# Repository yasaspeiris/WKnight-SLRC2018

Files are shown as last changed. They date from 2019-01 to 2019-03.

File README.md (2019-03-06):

# WKnight-SLRC2018



WKnight was made to compete in the Sri Lankan Robotics Challenge organized by the University of Moratuwa. 
The structure of this repo is as follows.

### Parts
Contains the STL files for the 3D printable parts. This includes the base, coin picking mechanism and gearing system.

3dp

### SLRC2019
This folder contains the code (for an Atmega2560). Each core component is split into a seperate .ino file. 

*colorsetup - Helper function for the colour sensor

*lightsandsw - Lights and switches

*main

*motorsetup - Contains motor control functions, white line/ wall / encoder PID Functions

*nrfsetup - NRF24L functions for wireless communication with a stationary robot

*path - path minimization

*QTRC - calibration and helper functions for the Pololu QTRC panel

*servosetup - servo control

*SLRC2019_19_Edited - global variables and definitions

*sonarsetup - ultrasonic sensor setup and control

*vlxsetup - TOF sensor (not used)

*wallfollow - wall following (not used)

### WKnightMEGA Breakout Board 
A breakout board for the Atmega2560 development board.



Full Instructions will be updated soon.

## Contributors
Pasindu Liyanage

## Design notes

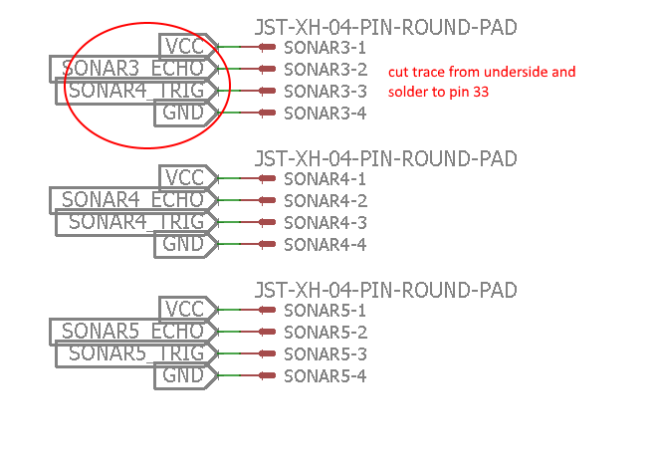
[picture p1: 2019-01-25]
WKnightMEGA - Breakout Board/sonarfix.png

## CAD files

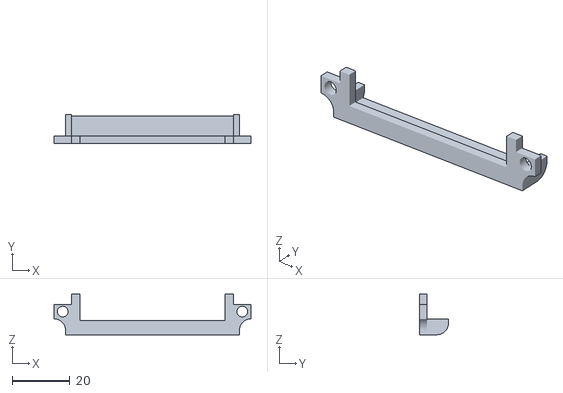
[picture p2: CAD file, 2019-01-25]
Parts/qtrcholder_main.STL
68.0 x 10.0 x 14.0

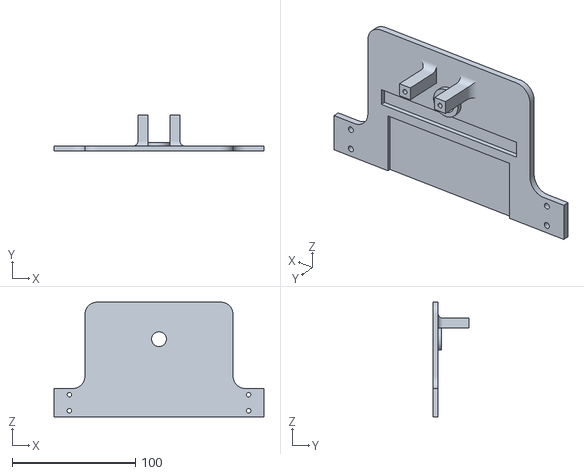
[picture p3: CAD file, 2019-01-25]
Parts/mainbed.STL
170.1 x 29.0 x 93.0

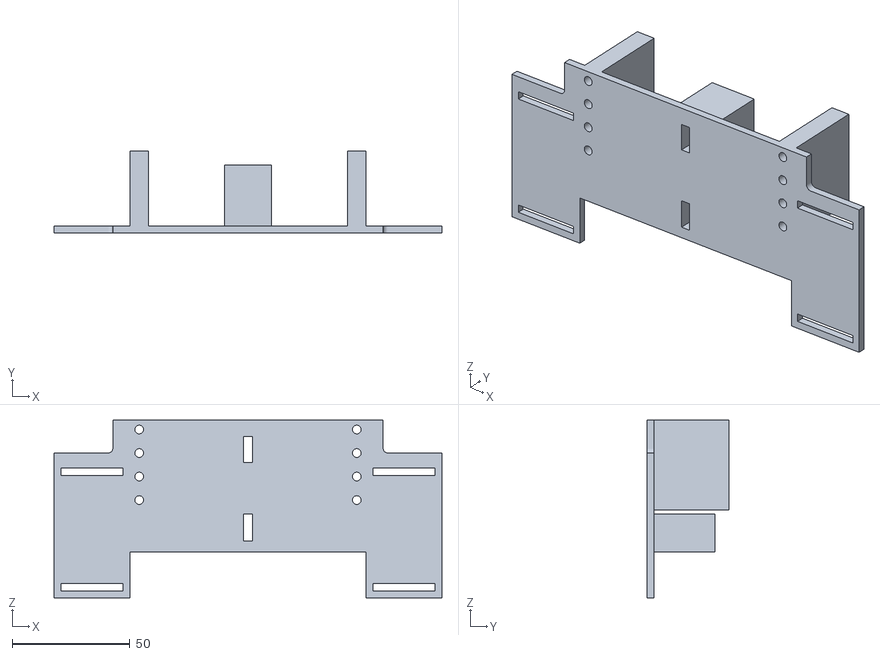
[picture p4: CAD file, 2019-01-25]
Parts/servomountfront.STL
165.0 x 35.0 x 75.6

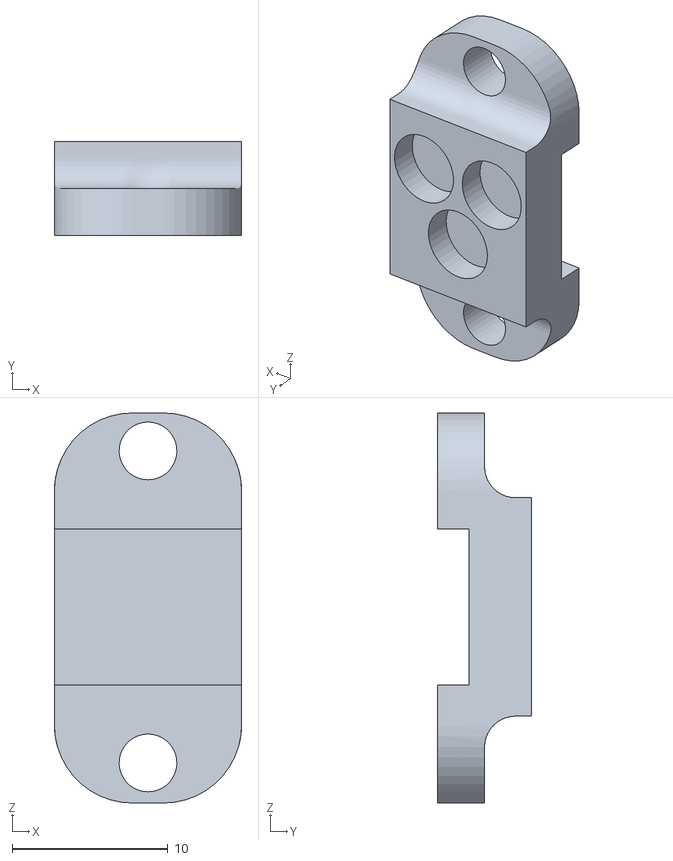
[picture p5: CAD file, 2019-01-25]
Parts/lightholder.STL
12.0 x 6.00 x 25.0

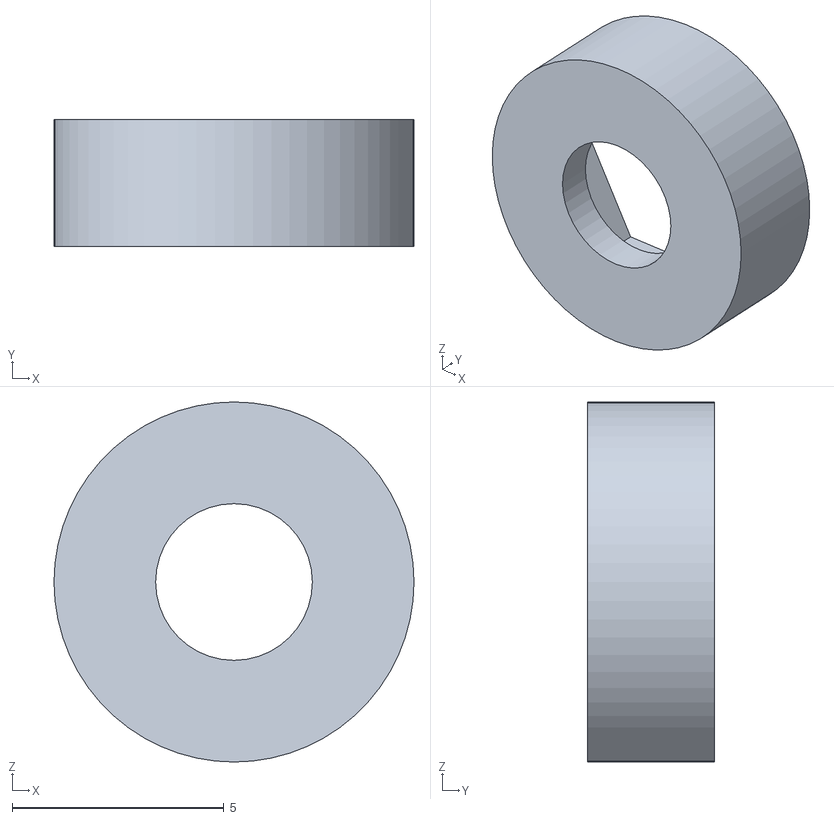
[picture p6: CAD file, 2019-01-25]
Parts/nutholder.STL
8.50 x 3.00 x 8.50

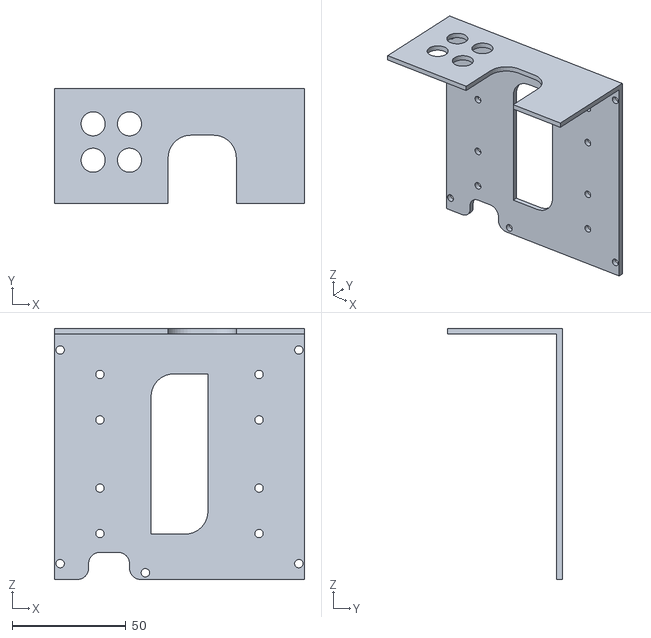
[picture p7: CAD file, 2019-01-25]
Parts/upper_cover.STL
110.0 x 50.5 x 110.5

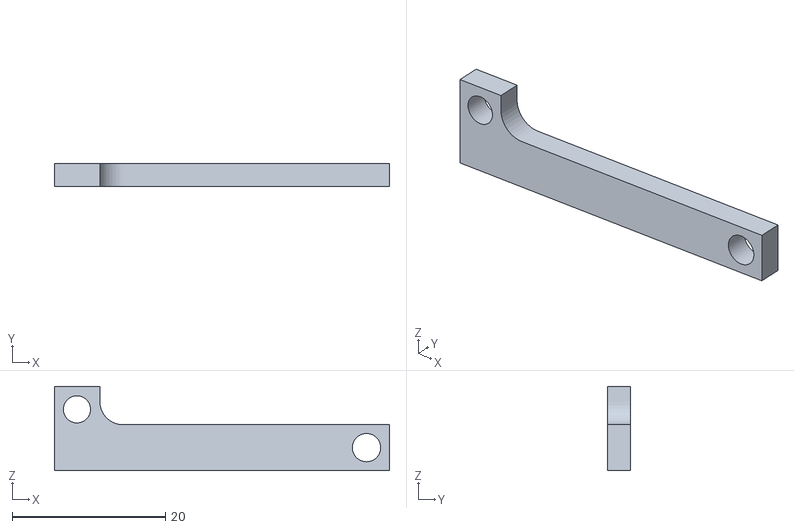
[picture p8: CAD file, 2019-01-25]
Parts/batlock.STL
43.8 x 3.00 x 11.0

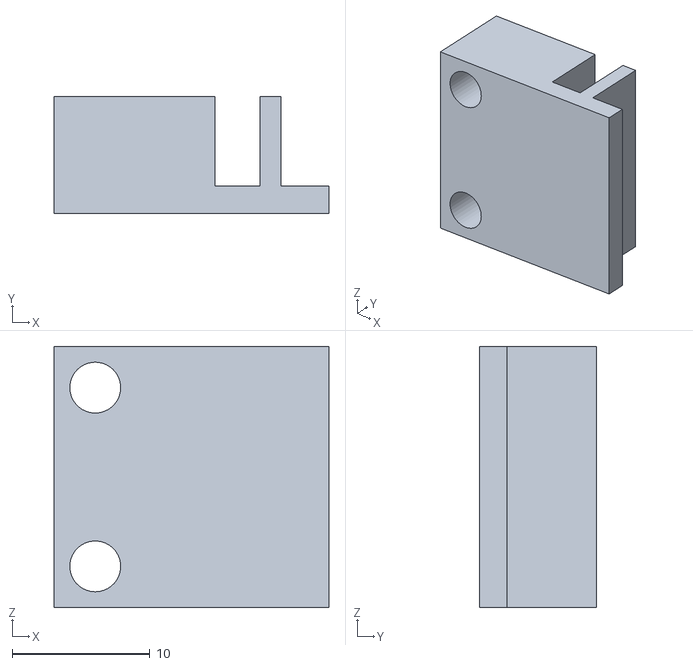
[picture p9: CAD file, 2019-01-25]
Parts/lockblock.STL
20.0 x 8.50 x 19.0

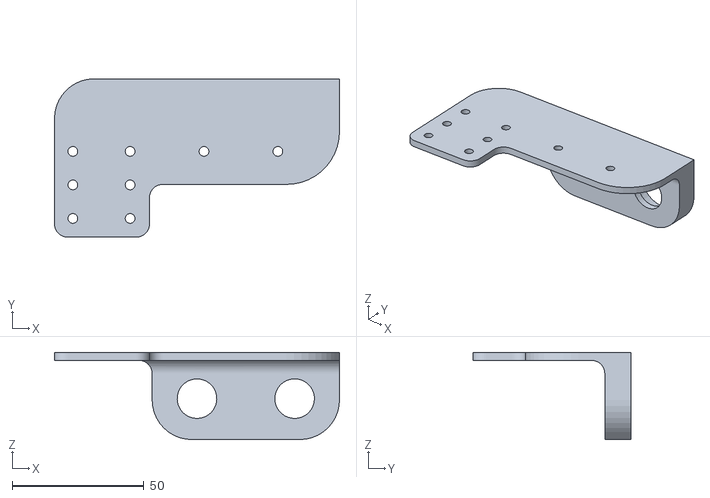
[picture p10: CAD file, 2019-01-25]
Parts/experimental_bracket.STL
108.0 x 60.0 x 33.0

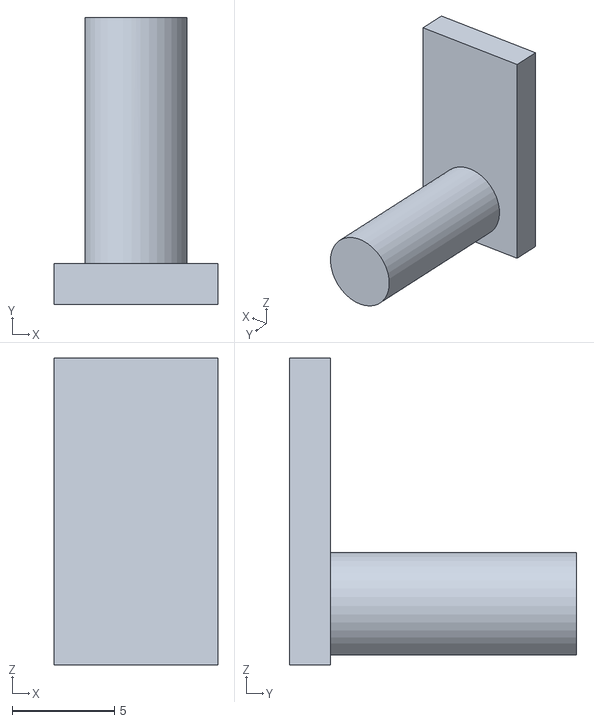
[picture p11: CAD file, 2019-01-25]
Parts/handle.STL
8.00 x 14.0 x 15.0

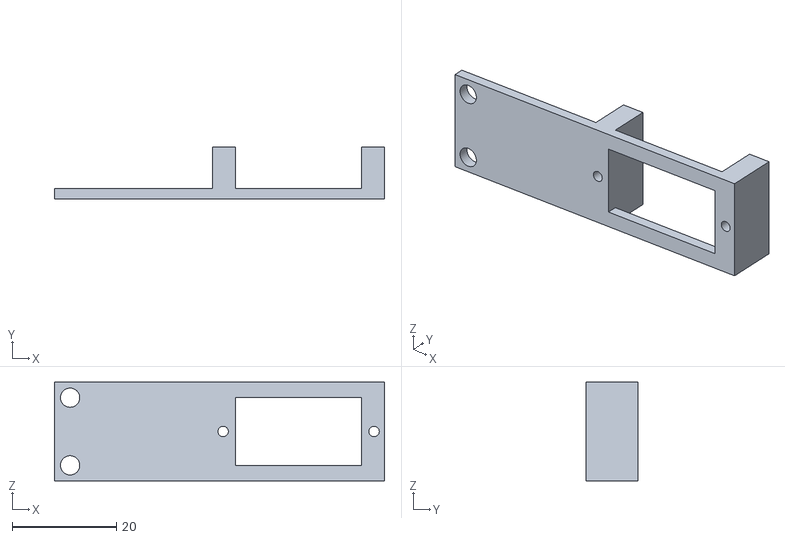
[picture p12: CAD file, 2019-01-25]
Parts/servoholder.STL
63.4 x 10.0 x 19.0

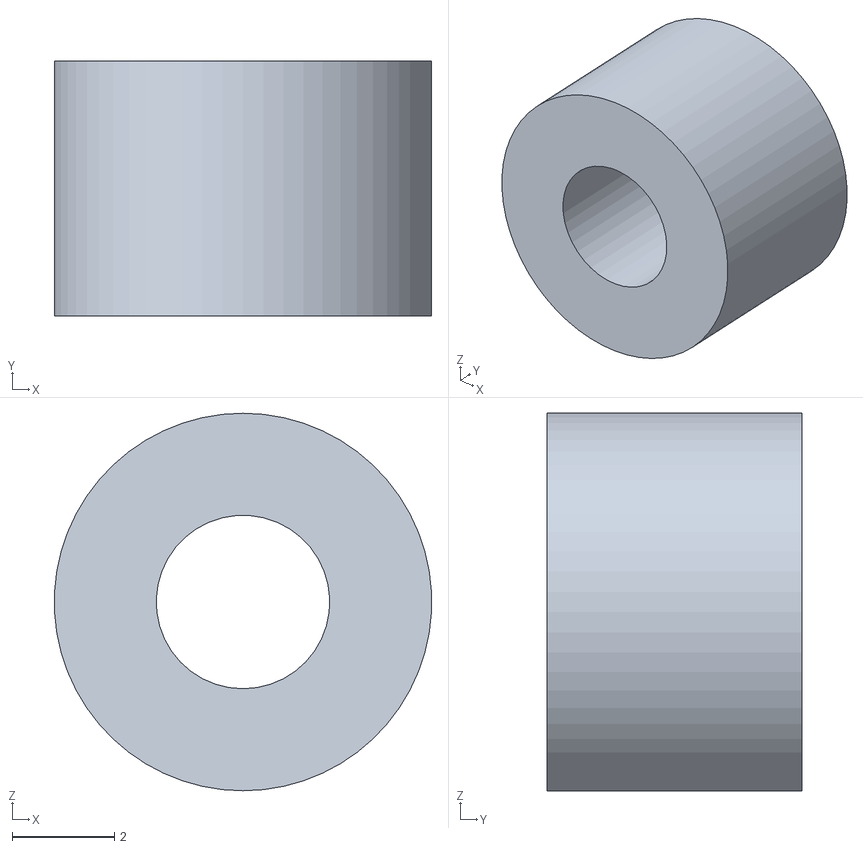
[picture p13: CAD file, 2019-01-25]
Parts/spacer2.STL
7.39 x 5.00 x 7.40

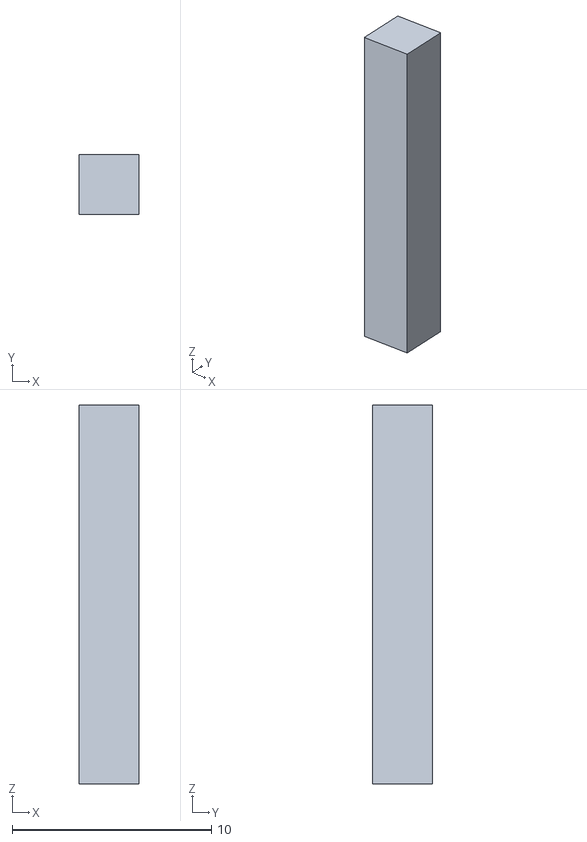
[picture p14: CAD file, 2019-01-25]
Parts/midspacer.STL
3.00 x 3.00 x 19.0

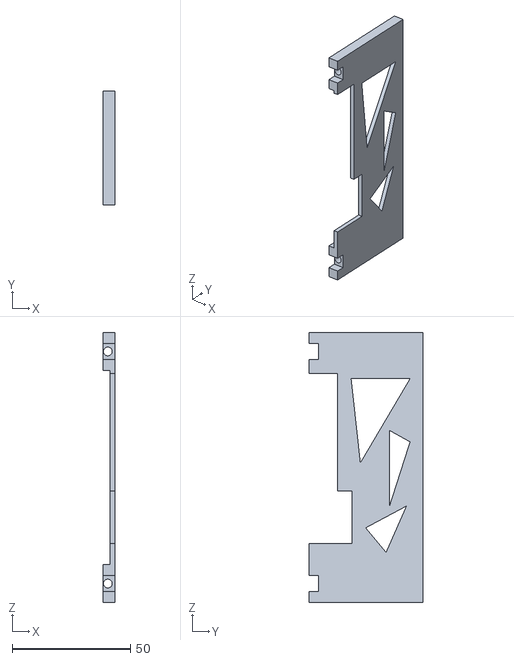
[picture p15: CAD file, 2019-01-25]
Parts/leftsidewall.STL
5.00 x 48.0 x 114.0

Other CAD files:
Parts/midgear.STL
Parts/rack1.STL
Parts/batterymount.STL
Parts/bearingspacer_new_2.STL
Parts/base.STL
Parts/base_top1-newnew.STL
Parts/coinremover.STL
Parts/compartment.STL
Parts/compcover1.STL
Parts/experimental_motorgear.STL
Parts/qtrcholder_sub.STL
Parts/rightsidewall.STL
Parts/spacer.STL
Parts/spurgear.STL
Parts/spurgear2.STL
Parts/trayeject.STL
Parts/wheelgear.STL

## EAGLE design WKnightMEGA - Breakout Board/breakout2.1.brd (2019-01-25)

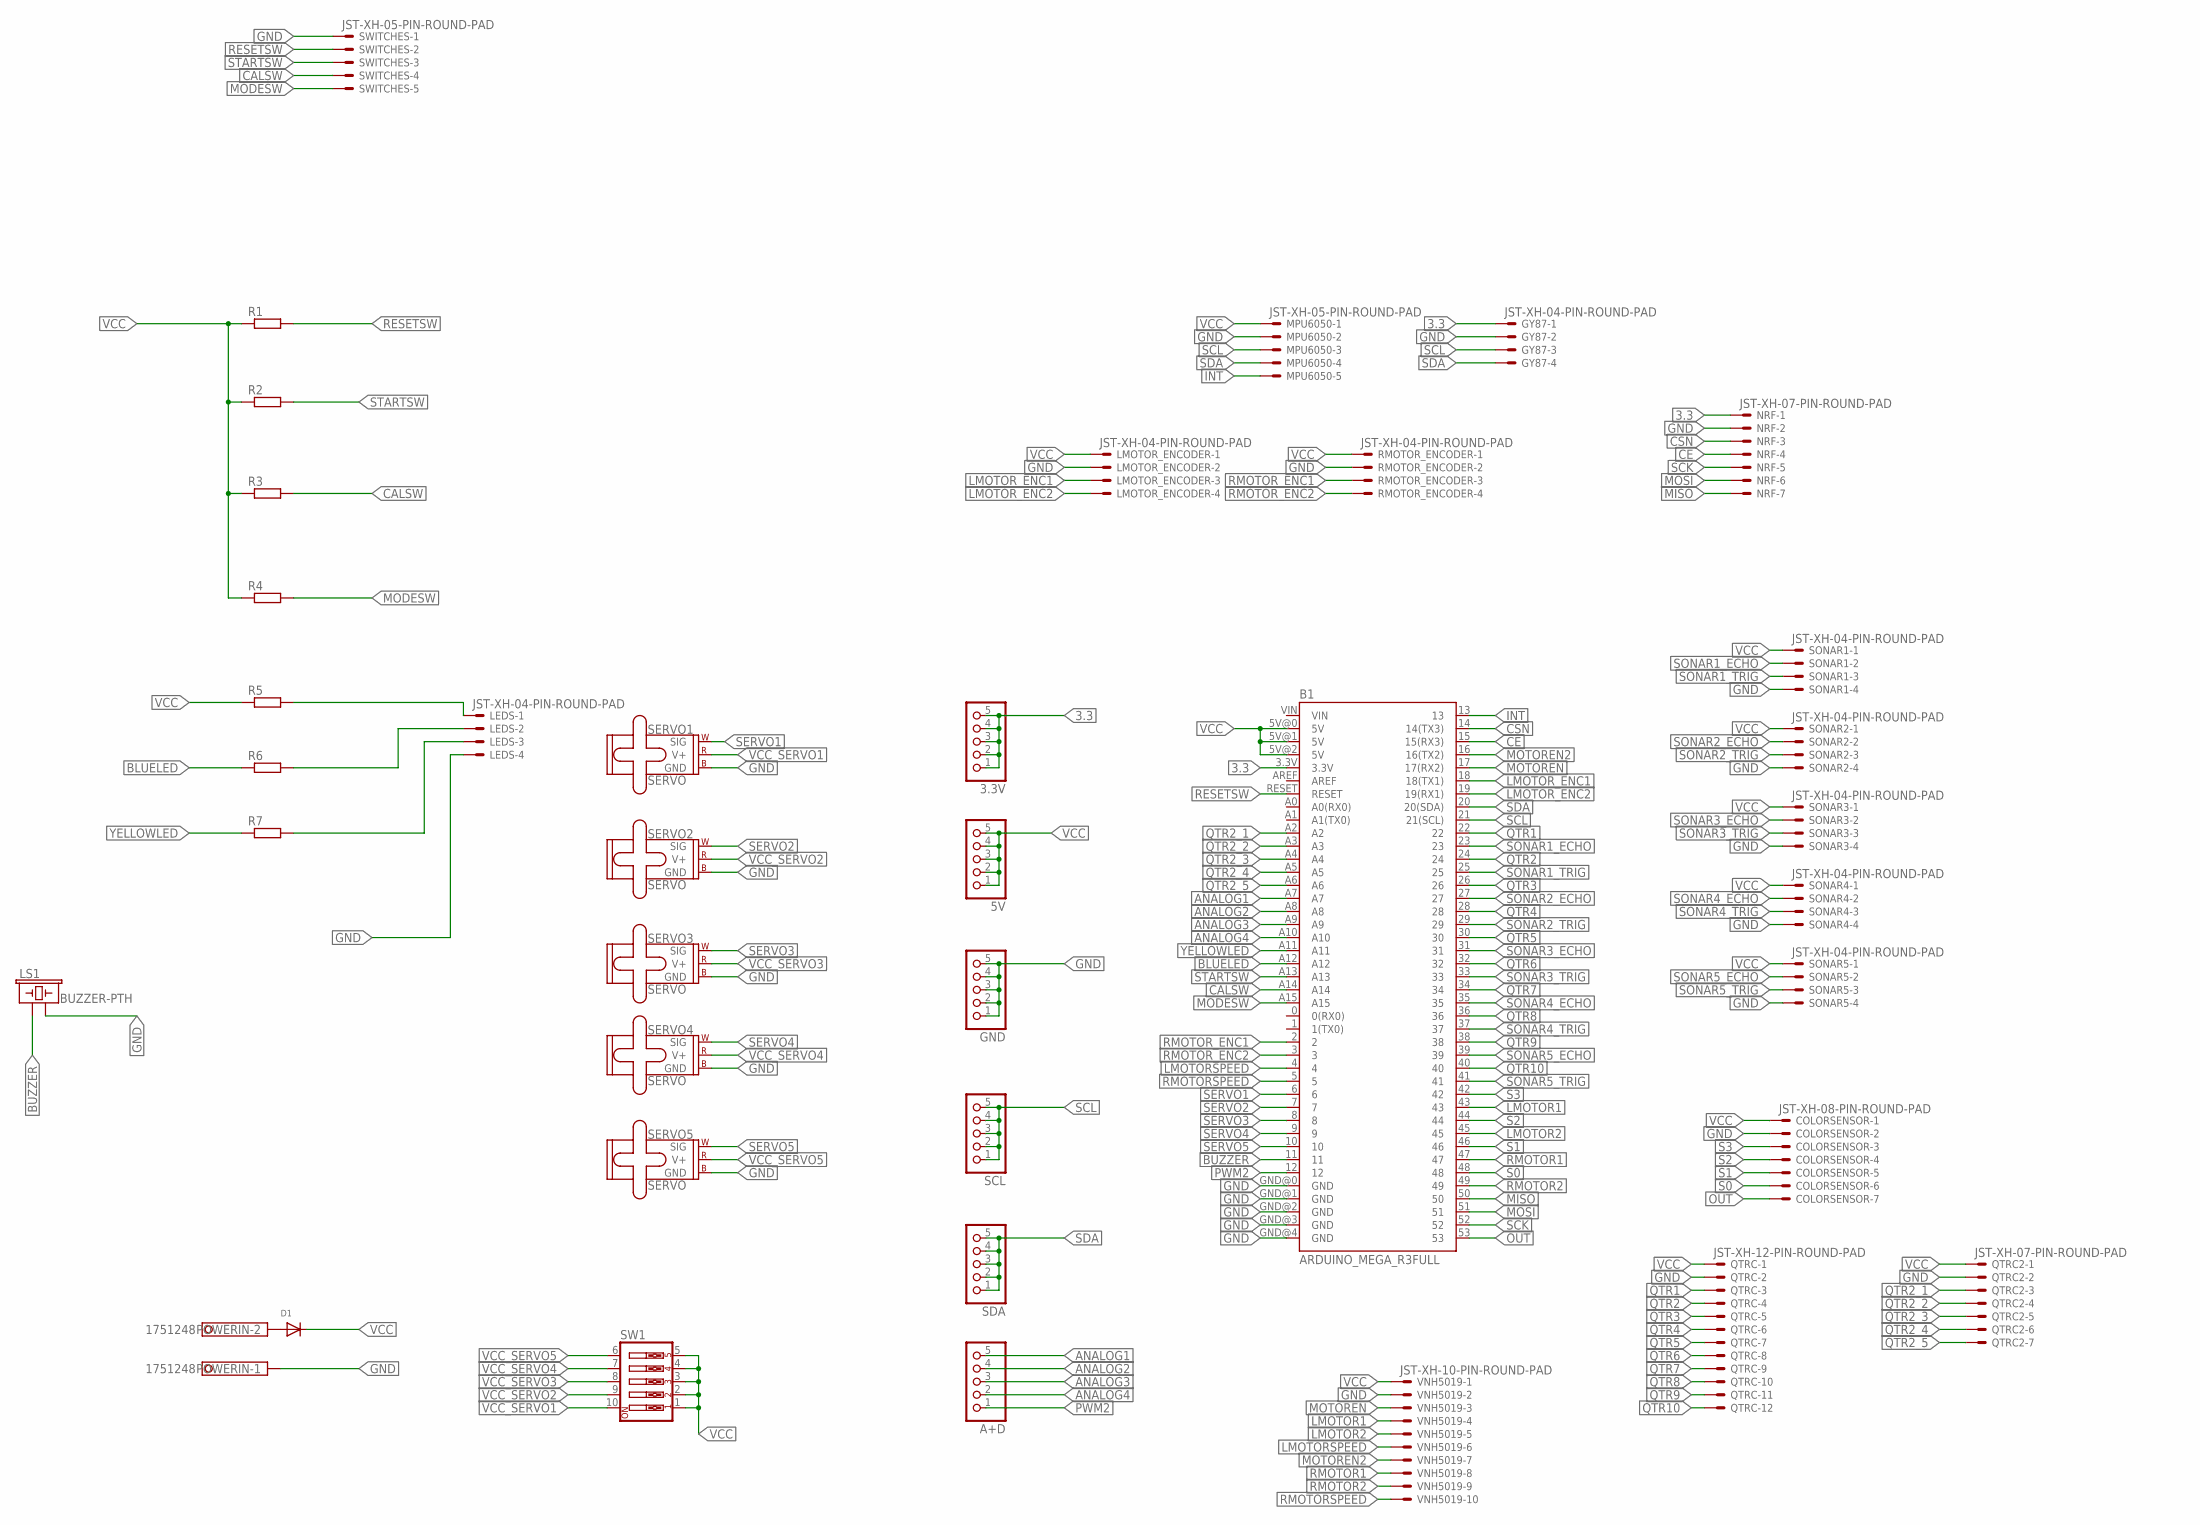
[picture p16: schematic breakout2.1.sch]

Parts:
3.3V, 5V: PINHD-1X55X2MM; 1_05X2MM
A+D: PINHD-1X55X2MM; 1_05X2MM
B1: ARDUINO_MEGA_R3FULL; ARDUINO_MEGA
COLORSENSOR: JST-XH-08-PIN-ROUND-PAD; JST-XH-08-PACKAGE-ROUND-PAD
D1: DIODEDO-1N4148; DO-1N4148
GND: PINHD-1X55X2MM; 1_05X2MM
GY87: JST-XH-04-PIN-ROUND-PAD; JST-XH-04-PACKAGE-ROUND-PAD
LEDS: JST-XH-04-PIN-ROUND-PAD; JST-XH-04-PACKAGE-ROUND-PAD
LMOTOR_ENCODER: JST-XH-04-PIN-ROUND-PAD; JST-XH-04-PACKAGE-ROUND-PAD
LS1: BUZZER-PTH; BUZZER-12MM
MPU6050: JST-XH-05-PIN-ROUND-PAD; JST-XH-05-PACKAGE-ROUND-PAD
NRF: JST-XH-07-PIN-ROUND-PAD; JST-XH-07-PACKAGE-ROUND-PAD
POWERIN: 1751248
QTRC: JST-XH-12-PIN-ROUND-PAD; JST-XH-12-PACKAGE-ROUND-PAD
QTRC2: JST-XH-07-PIN-ROUND-PAD; JST-XH-07-PACKAGE-ROUND-PAD
R1, R2, R3, R4, R5, R6, R7: R-EU_0204/7; 0204/7
RMOTOR_ENCODER: JST-XH-04-PIN-ROUND-PAD; JST-XH-04-PACKAGE-ROUND-PAD
SCL: PINHD-1X55X2MM; 1_05X2MM
SDA: PINHD-1X55X2MM; 1_05X2MM
SERVO1, SERVO2, SERVO3, SERVO4, SERVO5: SERVO; 1X03
SONAR1, SONAR2, SONAR3, SONAR4, SONAR5: JST-XH-04-PIN-ROUND-PAD; JST-XH-04-PACKAGE-ROUND-PAD
SW1: SW_DIP-5; EDG-05
SWITCHES: JST-XH-05-PIN-ROUND-PAD; JST-XH-05-PACKAGE-ROUND-PAD
VNH5019: JST-XH-10-PIN-ROUND-PAD; JST-XH-10-PACKAGE-ROUND-PAD

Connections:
3.3: 3.3V.1, 3.3V.2, 3.3V.3, 3.3V.4, 3.3V.5, B1.3.3V, GY87.1, NRF.1
ANALOG1: A+D.5, B1.A7
ANALOG2: A+D.4, B1.A8
ANALOG3: A+D.3, B1.A9
ANALOG4: A+D.2, B1.A10
BLUELED: B1.A12, R6.1
BUZZER: B1.11, LS1.+ (1)
CALSW: B1.A14, R3.2, SWITCHES.4
CE: B1.15 (15(RX3)), NRF.4
CSN: B1.14 (14(TX3)), NRF.3
GND: B1.GND@0 (GND), B1.GND@1 (GND), B1.GND@2 (GND), B1.GND@3 (GND), B1.GND@4 (GND), COLORSENSOR.2, GND.1, GND.2, GND.3, GND.4, GND.5, GY87.2, LEDS.4, LMOTOR_ENCODER.2, LS1.- (2), MPU6050.2, NRF.2, POWERIN.1, QTRC.2, QTRC2.2, RMOTOR_ENCODER.2, SERVO1.3 (GND), SERVO2.3 (GND), SERVO3.3 (GND), SERVO4.3 (GND), SERVO5.3 (GND), SONAR1.4, SONAR2.4, SONAR3.4, SONAR4.4, SONAR5.4, SWITCHES.1, VNH5019.2
INT: B1.13, MPU6050.5
LMOTOR1: B1.43, VNH5019.4
LMOTOR2: B1.45, VNH5019.5
LMOTORSPEED: B1.4, VNH5019.6
LMOTOR_ENC1: B1.18 (18(TX1)), LMOTOR_ENCODER.3
LMOTOR_ENC2: B1.19 (19(RX1)), LMOTOR_ENCODER.4
MISO: B1.50, NRF.7
MODESW: B1.A15, R4.2, SWITCHES.5
MOSI: B1.51, NRF.6
MOTOREN: B1.17 (17(RX2)), VNH5019.3
MOTOREN2: B1.16 (16(TX2)), VNH5019.7
unnamed: D1.A, POWERIN.2
unnamed: LEDS.2, R6.2
unnamed: LEDS.3, R7.2
unnamed: LEDS.1, R5.2
OUT: B1.53, COLORSENSOR.7
PWM2: A+D.1, B1.12
QTR1: B1.22, QTRC.3
QTR2: B1.24, QTRC.4
QTR2_1: B1.A2, QTRC2.3
QTR2_2: B1.A3, QTRC2.4
QTR2_3: B1.A4, QTRC2.5
QTR2_4: B1.A5, QTRC2.6
QTR2_5: B1.A6, QTRC2.7
QTR3: B1.26, QTRC.5
QTR4: B1.28, QTRC.6
QTR5: B1.30, QTRC.7
QTR6: B1.32, QTRC.8
QTR7: B1.34, QTRC.9
QTR8: B1.36, QTRC.10
QTR9: B1.38, QTRC.11
QTR10: B1.40, QTRC.12
RESETSW: B1.RESET, R1.2, SWITCHES.2
RMOTOR1: B1.47, VNH5019.8
RMOTOR2: B1.49, VNH5019.9
RMOTORSPEED: B1.5, VNH5019.10
RMOTOR_ENC1: B1.2, RMOTOR_ENCODER.3
RMOTOR_ENC2: B1.3, RMOTOR_ENCODER.4
S0: B1.48, COLORSENSOR.6
S1: B1.46, COLORSENSOR.5
S2: B1.44, COLORSENSOR.4
S3: B1.42, COLORSENSOR.3
SCK: B1.52, NRF.5
SCL: B1.21 (21(SCL)), GY87.3, MPU6050.3, SCL.1, SCL.2, SCL.3, SCL.4, SCL.5
SDA: B1.20 (20(SDA)), GY87.4, MPU6050.4, SDA.1, SDA.2, SDA.3, SDA.4, SDA.5
SERVO1: B1.6, SERVO1.1 (SIG)
SERVO2: B1.7, SERVO2.1 (SIG)
SERVO3: B1.8, SERVO3.1 (SIG)
SERVO4: B1.9, SERVO4.1 (SIG)
SERVO5: B1.10, SERVO5.1 (SIG)
SONAR1_ECHO: B1.23, SONAR1.2
SONAR1_TRIG: B1.25, SONAR1.3
SONAR2_ECHO: B1.27, SONAR2.2
SONAR2_TRIG: B1.29, SONAR2.3
SONAR3_ECHO: B1.31, SONAR3.2
SONAR3_TRIG: B1.33, SONAR3.3
SONAR4_ECHO: B1.35, SONAR4.2
SONAR4_TRIG: B1.37, SONAR4.3
SONAR5_ECHO: B1.39, SONAR5.2
SONAR5_TRIG: B1.41, SONAR5.3
STARTSW: B1.A13, R2.2, SWITCHES.3
VCC: 5V.1, 5V.2, 5V.3, 5V.4, 5V.5, B1.5V@0 (5V), B1.5V@1 (5V), B1.5V@2 (5V), COLORSENSOR.1, D1.C, LMOTOR_ENCODER.1, MPU6050.1, QTRC.1, QTRC2.1, R1.1, R2.1, R3.1, R4.1, R5.1, RMOTOR_ENCODER.1, SONAR1.1, SONAR2.1, SONAR3.1, SONAR4.1, SONAR5.1, SW1.1, SW1.2, SW1.3, SW1.4, SW1.5, VNH5019.1
VCC_SERVO1: SERVO1.2 (V+), SW1.10
VCC_SERVO2: SERVO2.2 (V+), SW1.9
VCC_SERVO3: SERVO3.2 (V+), SW1.8
VCC_SERVO4: SERVO4.2 (V+), SW1.7
VCC_SERVO5: SERVO5.2 (V+), SW1.6
YELLOWLED: B1.A11, R7.1

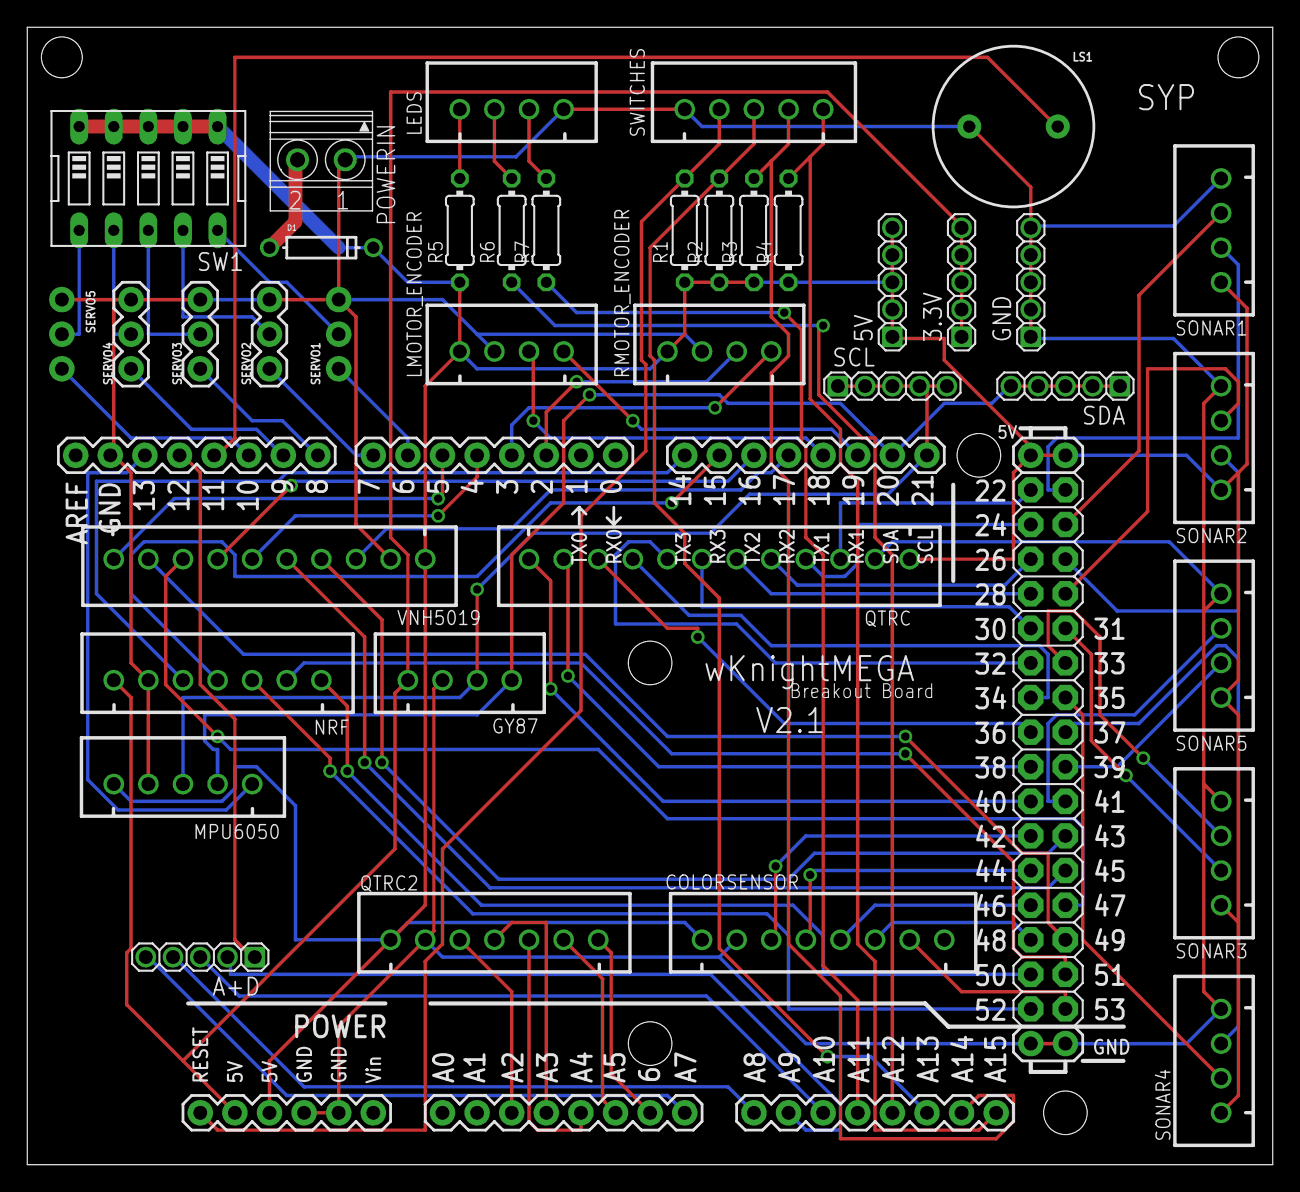
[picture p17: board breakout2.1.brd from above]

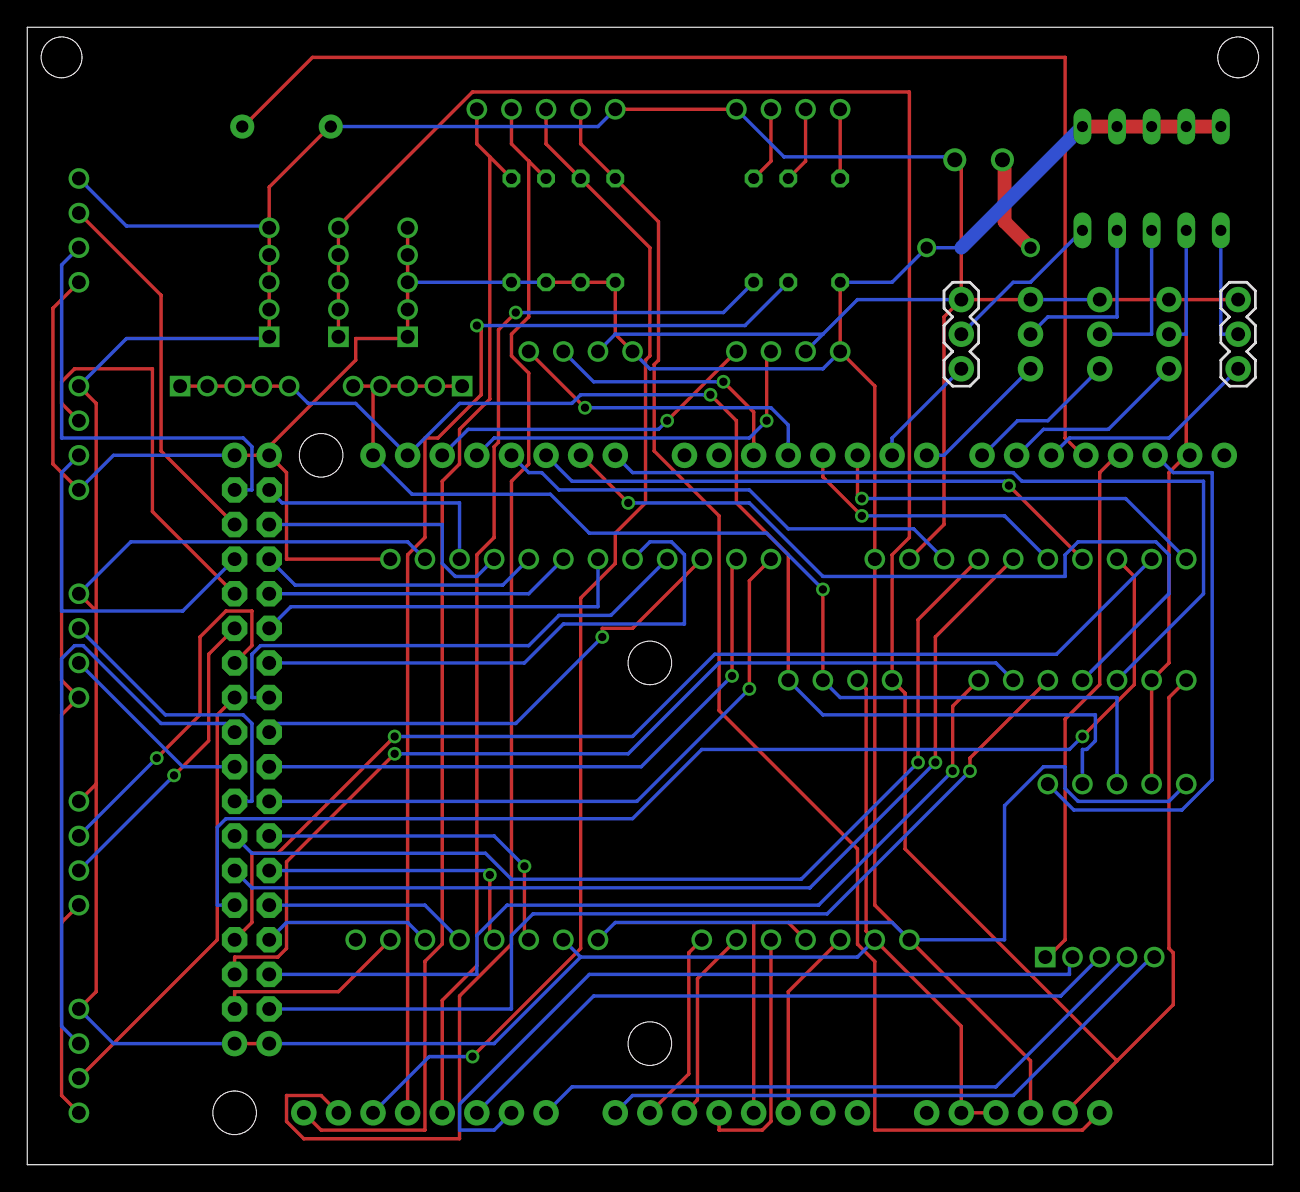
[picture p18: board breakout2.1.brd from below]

Board: 2 copper layers, 91.4 x 83.5 mm, 39 parts (2 on the bottom side), 79 nets.

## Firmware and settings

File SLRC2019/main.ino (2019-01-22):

void setup() {
  Serial.begin(115200);
  lightsandswsetup();
  motorsetup();
  servosetup();
  colorsensorsetup();
  nrfsetup();
  //vlxsetup();
}

void loop() {
  int val1 = digitalRead(STARTSWITCH);
  int val2 = digitalRead(MODESW);
  int val3 = digitalRead(CALSW);

  char c = checkcolor();
  

  if ( val1 == 0) {
    digitalWrite(BLUELED, HIGH);
    nrfsendCmd('s');
    nrfsendCmd('s');
    //nrfsendSum(0);
    delay(1000);
    digitalWrite(BLUELED, LOW);

    delay(2000);


    SetMasterPower(55); SetSlavePower(55); // Exit white Box
    QTRCRead();
    SetMasterPower(60); SetSlavePower(60);
    while (SensorPanelVal == 1023) {
      QTRCRead();
    }
    delay(69); //hehe
    setBrakes(255, 255);

    maze_solve();
    delay(PADDING);
    //Now at end of maze


    QTRCRead();
    SetMasterPower(-60); SetSlavePower(-60);
    while (SensorPanelVal == 1023) {
      QTRCRead();
    }
    setBrakes(255, 255);
    reverseline(60, 600);
    delay(PADDING);//bring out of box
    linedegreetravel('R', TURNSPEED);
    delay(PADDING); //turn around


    which_turn = 1; //signal that this is the path to simplify
    maze_solve();
    delay(PADDING);
    //now back at starting square

    QTRCRead();
    SetMasterPower(-60); SetSlavePower(-60);
    while (SensorPanelVal == 1023) {
      QTRCRead();
    }
    setBrakes(255, 255);
    reverseline(60, 600);
    delay(PADDING);
    //bring out of white square

    linedegreetravel('L', TURNSPEED);
    delay(PADDING);
    //turn

    which_turn = 2;
    if (which_turn == 2) {
      if (totalSum % 2 == 0) {
        nrfsendCmd('r');
      } else {
        nrfsendCmd('l');
      }
    }
    digitalWrite(GREENLED,HIGH);
    gotostart();
    delay(PADDING);
    digitalWrite(GREENLED,LOW);
    

    QTRCRead();
    SetMasterPower(60); SetSlavePower(60);
    while (SensorPanelVal == 1023) {
      QTRCRead();
    }
    delay(69);
    setBrakes(255, 255);
    delay(PADDING);
    nodetravelcurve(40); // ALL OKAY UP TO HERE


    
    QTRCRead();
    SetMasterPower(60); SetSlavePower(60);
    while (SensorPanelVal == 1023) {
      QTRCRead();
    } //bypass 10 cm line
    delay(400);
    setBrakes(255, 255);
    delay(PADDING);

    

    temp = nodetravel(55);
    delay(PADDING); //at beginning of square
    

    if (totalSum % 2 == 0) {
      linedegreetravel('R', TURNSPEED);
      delay(PADDING);
      temp = nodetravel(55);
      delay(PADDING);
      linedegreetravel('R', TURNSPEED);
      delay(PADDING);

    } else {
      linedegreetravel('L', TURNSPEED);
      delay(PADDING);
      temp = nodetravel(55);
      delay(PADDING);
      linedegreetravel('L', TURNSPEED);
      delay(PADDING);

    }

    //unloading

    which_turn = 5;
    
    temp = nodetravel(55);
    delay(PADDING);

    linedegreetravel('L',TURNSPEED);
    delay(PADDING);
    temp = nodetravel(45);
    delay(PADDING);
    raise_cointray();
    lower_cointray();
    raise_cointray();
    lower_cointray();
    delay(700);
    analogWrite(11, 120);
    delay(20);
    reverseline(60, 500);
    delay(PADDING);
    linedegreetravel('L',TURNSPEED);
    delay(PADDING);


    nodetravel(55);
    delay(PADDING);

    linedegreetravel('L',TURNSPEED);
    delay(PADDING);
    nodetravel(45);
    delay(PADDING);
    opengreen();
    delay(200);
    raise_cointray();
    lower_cointray();
    raise_cointray();
    lower_cointray();
    delay(700);
    closepanes();

    analogWrite(11, 120);
    delay(20);
    reverseline(60, 500);
    delay(PADDING);
    linedegreetravel('L',TURNSPEED);
    delay(PADDING);


    nodetravel(55);
    delay(PADDING);


    linedegreetravel('L',TURNSPEED);
    delay(PADDING);
    nodetravel(45);
    delay(PADDING);
    openblue();
    delay(200);
    raise_cointray();
    lower_cointray();
    raise_cointray();
    lower_cointray();
    closepanes();

    analogWrite(11, 120);
    delay(20);
    analogWrite(11, 120);
    delay(20);
    analogWrite(11, 120);
    delay(20);
    analogWrite(11, 120);
    delay(20); 
    



  }

  if (val3 == 0) {
    digitalWrite(YELLOWLED, HIGH);
    QTRCcallibrate();
    digitalWrite(YELLOWLED, LOW);
  }
  if (val2 == 0) {
    delay(1000);
    nodetravelcurve(40);
  }

}

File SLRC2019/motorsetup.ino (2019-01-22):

/*Motor driver functions -
  contains -
  motorsetup() - always run at setup
  SetMasterPower(int MasterPower) - set Master(left) pwm + front - back
  SetSlavePower (int SlavePower) - set Slave(right) pwm + front - back
  inchtravel(int distance,int +-power) - encoded movementfor provided inches/10
  MaintainMovement() - only run inside mmtravel,inchtravel,sharpleft or sharpright,angleturn
  StopMovement() - stop motors
*/

void motorsetup() {
  // put your setup code here, to run once:
  pinMode(LMOTORSPEED, OUTPUT); pinMode(RMOTORSPEED, OUTPUT);
  analogWrite(LMOTORSPEED, 0); analogWrite(RMOTORSPEED, 0);

  pinMode(RMOTOR1, OUTPUT); pinMode(RMOTOR2, OUTPUT);
  digitalWrite(RMOTOR1, LOW); digitalWrite(RMOTOR2, LOW);

  pinMode(LMOTOR1, OUTPUT); pinMode(LMOTOR2, OUTPUT);
  digitalWrite(LMOTOR1, LOW); digitalWrite(LMOTOR2, LOW);

  pinMode(MOTOREN, OUTPUT);
  digitalWrite(MOTOREN, HIGH);

  pinMode(MOTOREN2, OUTPUT);
  digitalWrite(MOTOREN2, HIGH);

}

/*===========================================================

  Set PWM - Set Master and Slave PWM - Master - Left Wheel

   ===========================================================
*/
void SetMasterPower(int MasterPower) {
  if (MasterPower < 0) {
    analogWrite(LMOTORSPEED, abs(MasterPower));
    digitalWrite(LMOTOR1, HIGH); digitalWrite(LMOTOR2, LOW);

  } else if (MasterPower > 0) {
    analogWrite(LMOTORSPEED, abs(MasterPower));
    digitalWrite(LMOTOR1, LOW); digitalWrite(LMOTOR2, HIGH);

  } else {
    digitalWrite(LMOTOR1, LOW ); digitalWrite(LMOTOR2, LOW);
  }
}

void SetSlavePower(int SlavePower) {
  if (SlavePower < 0) {
    analogWrite(RMOTORSPEED, abs(SlavePower));

    digitalWrite(RMOTOR1, HIGH); digitalWrite(RMOTOR2, LOW);

  } else if (SlavePower > 0) {
    analogWrite(RMOTORSPEED, abs(SlavePower));
    digitalWrite(RMOTOR1, LOW); digitalWrite(RMOTOR2, HIGH);

  } else {
    digitalWrite(RMOTOR1, LOW); digitalWrite(RMOTOR2, LOW);
  }
}



/*===================================================================

          // Line - nodetravel,nodetravelnostop, linetravel,alligntoline

  ===================================================================== */

char nodetravel(int power) {
  nodeflag = 0;
  char doaction2;
  MasterENC.write(0) ; SlaveENC.write(0); totalTicks = 0; error = 0; lasterror = 0; SensorPanelVal = 0;
  MaxPower = power;
  MasterPower = power; SlavePower = power;
  while (nodeflag == 0) {
    doaction2 = MaintainLineMovement();
  }
  setBrakes(255, 255);
  analogWrite(11, 120);
  delay(20);
  analogWrite(11, 0);
  MaxPower = 0;
  return doaction2;
}

void nodetravelcurve(int power) {
  nodeflag = 0;
  MasterENC.write(0) ; SlaveENC.write(0); totalTicks = 0; error = 0; lasterror = 0; SensorPanelVal = 0;
  MaxPower = power;
  MasterPower = power; SlavePower = power;
  while (nodeflag == 0) {
    MaintainCurvedLineMovement();
  }
  setBrakes(255, 255);
  analogWrite(11, 120);
  delay(20);
  analogWrite(11, 0);
  MaxPower = 0;
}


void linetravel(int distance, int power) { //Travel along the line for some distance
  nodeflag = 0;
  int tickGoal = distance;
  MasterENC.write(0) ; SlaveENC.write(0); totalTicks = 0; error = 0; lasterror = 0;
  MaxPower = power;
  MasterPower = power; SlavePower = power;

  while (nodeflag == 0) {
    MaintainTickLineMovement();
  }
  setBrakes(255, 255); //StopMotors
  analogWrite(11, 120);
  delay(20);
  analogWrite(11, 0);
  MaxPower = 0;
}


/*===================================================================

          // Encoder travel - inchtravel, inchtravelnostop,mmtravel

  ===================================================================== */
void inchtravel(float distance, int power) {
  int tickGoal = (128 * (distance)); int i;
  MasterENC.write(0) ; SlaveENC.write(0); totalTicks = 0; error = 0; lasterror = 0;
  MaxPower = power;
  MasterPower = power; SlavePower = power;

  while (abs(totalTicks) <  tickGoal) {
    MaintainMovement();
    if (totalTicks > 3 / 4 * tickGoal) {
      MaxPower = power / 2;
    }
  }
  setBrakes(255, 255);
}

/*===================================================================

          // Degree Travel - degreetravel

  ===================================================================== */

void degreetravel(int degree, int power) {
  int tickGoal = abs(degree) * 9.89 ;//compensation
  MasterENC.write(0) ; SlaveENC.write(0); totalTicks = 0;
  if (degree > 0) { //left turn
    SetMasterPower(-1 * power); SetSlavePower(power);
    while (MasterENC.read() > (-1 * tickGoal) || SlaveENC.read() < tickGoal) {
      if (SlaveENC.read() > 3 / 4 * tickGoal) {
        SetMasterPower(-1 * power / 2); SetSlavePower(power / 2);
      }
    }
    setBrakes(255, 255);
  } else if (degree < 0) {
    MasterENC.write(0) ; SlaveENC.write(0); totalTicks = 0;
    SetMasterPower( power); SetSlavePower(-power);
    while (MasterENC.read() < tickGoal || SlaveENC.read() > (-1 * tickGoal)) {
      if (MasterENC.read() > 3 / 4 * tickGoal) {
        SetMasterPower(power / 2); SetSlavePower(-1 * power / 2);
      }
    }
    setBrakes(255, 255);

  }
}

void linedegreetravel(char degree, int power) {
  int tickGoal = 1000 ;//compensation
  MasterENC.write(0) ; SlaveENC.write(0);
  if (degree == 'L') { //left turn
    SetMasterPower(-1 * power); SetSlavePower(power);
    while (MasterENC.read() > (-1 * tickGoal) || SlaveENC.read() < tickGoal) {
      QTRCRead();
    }
    SetMasterPower(-1 * power / 2); SetSlavePower(power / 2);
    while (1) {
      QTRCRead();
      if (sensorRead[3]) {
        break;
      }
    }
    setBrakes(255, 255);
  } else if (degree == 'R') {
    SetMasterPower( power); SetSlavePower(-power);
    while (MasterENC.read() < tickGoal || SlaveENC.read() > (-1 * tickGoal)) {
      QTRCRead();
    }
    SetMasterPower( power / 2); SetSlavePower(-power / 2);
    while (1) {
      QTRCRead();
      if (sensorRead[4]) {
        break;
      }
    }
    setBrakes(255, 255);

  }
}

void reverseline(int power, int ticks) {
  MasterENC.write(0) ; SlaveENC.write(0); totalTicks = 0;
  MaxPower = -power;
  MasterPower = -power; SlavePower = -power
                                     ;
  SetMasterPower(MasterPower); SetSlavePower(SlavePower);
  while (MasterENC.read() > -1 * ticks) {
    QTRCRead();
  }
  setBrakes(255, 255);
  analogWrite(11, 120);
  delay(20);
  analogWrite(11, 0);
  MaxPower = 0;
}
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

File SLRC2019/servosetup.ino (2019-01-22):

/* Servo setup -
   servosetup()
   pickup()
   putdown()
*/

void servosetup() {

  pwm.begin();
  pwm.setPWMFreq(60);  // Analog servos run at ~60 Hz updates
  delay(10);
  for (int m = 0 ; m < 3; m++) {
    digitalWrite(YELLOWLED, HIGH);
    delay(500);
    digitalWrite(YELLOWLED, LOW);
    delay(500);
  }

  setServo(COINTOSSERRIGHT,16);//Set coin tray to zero position
  setServo_invert(COINTOSSERLEFT,16);

  setServo(EJECTRIGHT, 5); //Set ejector servos to zero
  setServo_invert(EJECTLEFT, 5);

  setServo(LEFTPANE, 0); //Set ejector servos to zero
  setServo(RIGHTPANE, 180);

  setServo(MAINARMRIGHT, 126);// Set magnetic bed to zero pos
  setServo_invert(MAINARMLEFT, 126);

  delay(1000);



}

///         MAIN ARM

void lower_mainarm() {
  for (int i = 124; i >= 12; i--) {
    setServo(MAINARMRIGHT, i+5);
    setServo_invert(MAINARMLEFT, i);
    delay(8);
  }

  delay(1000);

}

void raise_mainarm() {
  for (int i = 12; i <= 124; i++) {
    setServo(MAINARMRIGHT, i+5);
    setServo_invert(MAINARMLEFT, i);
    delay(8);
  }

  delay(1000);

}

//      COIN TRAY

void raise_cointray() {
  setServo(COINTOSSERRIGHT, 80);
  setServo_invert(COINTOSSERLEFT, 80);
  delay(500);
}

void lower_cointray() {
  setServo(COINTOSSERRIGHT, 20);
  setServo_invert(COINTOSSERLEFT, 20);
  delay(500);
}

void shake_cointray(){
  setServo(COINTOSSERRIGHT, 20);
  setServo_invert(COINTOSSERLEFT, 20);
  delay(200);

  setServo(COINTOSSERRIGHT, 40);
  setServo_invert(COINTOSSERLEFT, 40);
  delay(200);

  setServo(COINTOSSERRIGHT, 20);
  setServo_invert(COINTOSSERLEFT, 20);
  delay(200);
  

  
}

//      COIN EJECTOR

void raise_coinejector() {
  setServo(EJECTRIGHT, 5);
  setServo_invert(EJECTLEFT, 5);
  delay(500);
}

void mid_coinejector(){
  setServo(EJECTRIGHT, 130);
  setServo_invert(EJECTLEFT, 130);
  delay(500);
}

void lower_coinejector(){
  setServo(EJECTRIGHT, 180);
  setServo_invert(EJECTLEFT, 180);
  delay(500);
}

//Servo Angle Assign Functions - PCA9685

void setServo(int channel, int angle) {
  if (angle < 0) {
    angle = 0;
  } else if (angle > 180) {
    angle = 180;
  }
  pwm.setPWM(channel, 0, (int)((angle * 2.5) + 150));
}

void setServo_invert(int channel, int angle) {
  if (angle < 0) {
    angle = 0;
  } else if (angle > 180) {
    angle = 180;
  }
  pwm.setPWM(channel, 0, (int)((angle * -2.5) + 600));
}

void openred(){
  setServo(LEFTPANE,0);
  setServo(RIGHTPANE,180);
  delay(300);
}

void opengreen(){
   setServo(LEFTPANE,180);
  setServo(RIGHTPANE,180);
  delay(500);
}

void openblue(){
   setServo(LEFTPANE,0);
  setServo(RIGHTPANE,0);
  delay(500);
}

void closepanes(){
  setServo(LEFTPANE,0);
  setServo(RIGHTPANE,180);
  delay(300);
}

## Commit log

2019-01-25 parts commit
    [base.STL, base_top1-newnew.STL, batlock.STL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]
2019-01-25 Breakout Board
    [breakout2.1.brd, breakout2.1.sch]

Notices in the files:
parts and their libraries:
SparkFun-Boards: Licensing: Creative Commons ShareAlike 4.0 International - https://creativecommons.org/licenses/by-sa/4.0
